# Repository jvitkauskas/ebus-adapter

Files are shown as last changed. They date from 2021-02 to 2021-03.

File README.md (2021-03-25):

# ebus-adapter

This is an open source reimplementation of adapter boards for [eBUS daemon project](https://github.com/john30/ebusd). Currently only base board v2.2 is provided.

# Base Board v2.2

! Please note this board has not been tested in real life yet !

This board was designed by [Daniel Ismail](https://github.com/daniism)

See https://ebus.github.io/adapter/base.en for more information.

EAGLE files are available in [baseboard_v2.2](baseboard_v2.2) directory.

Fabrication files (Gerber files) are available in [baseboard_v2.2/Fabrication_Files.zip](baseboard_v2.2/Fabrication_Files.zip)

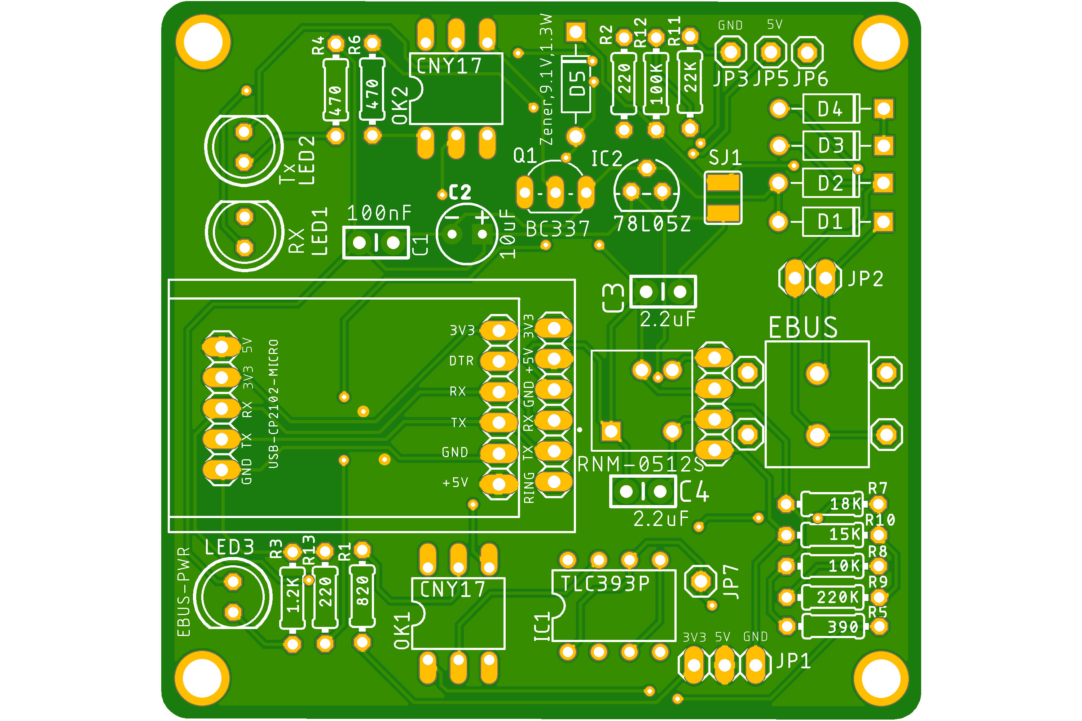
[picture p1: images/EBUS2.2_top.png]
Base Board v2.2 top image


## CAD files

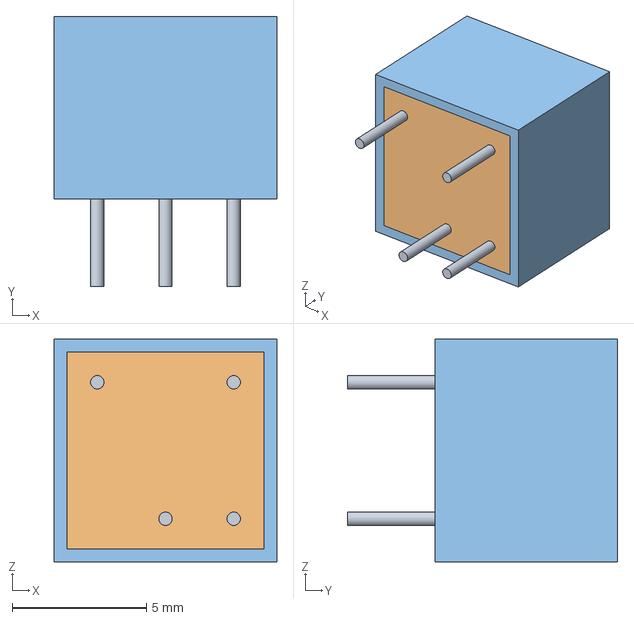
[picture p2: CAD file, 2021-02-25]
baseboard_v2.2/RNM-0512S.STEP
8.30 x 10.1 x 8.30 mm

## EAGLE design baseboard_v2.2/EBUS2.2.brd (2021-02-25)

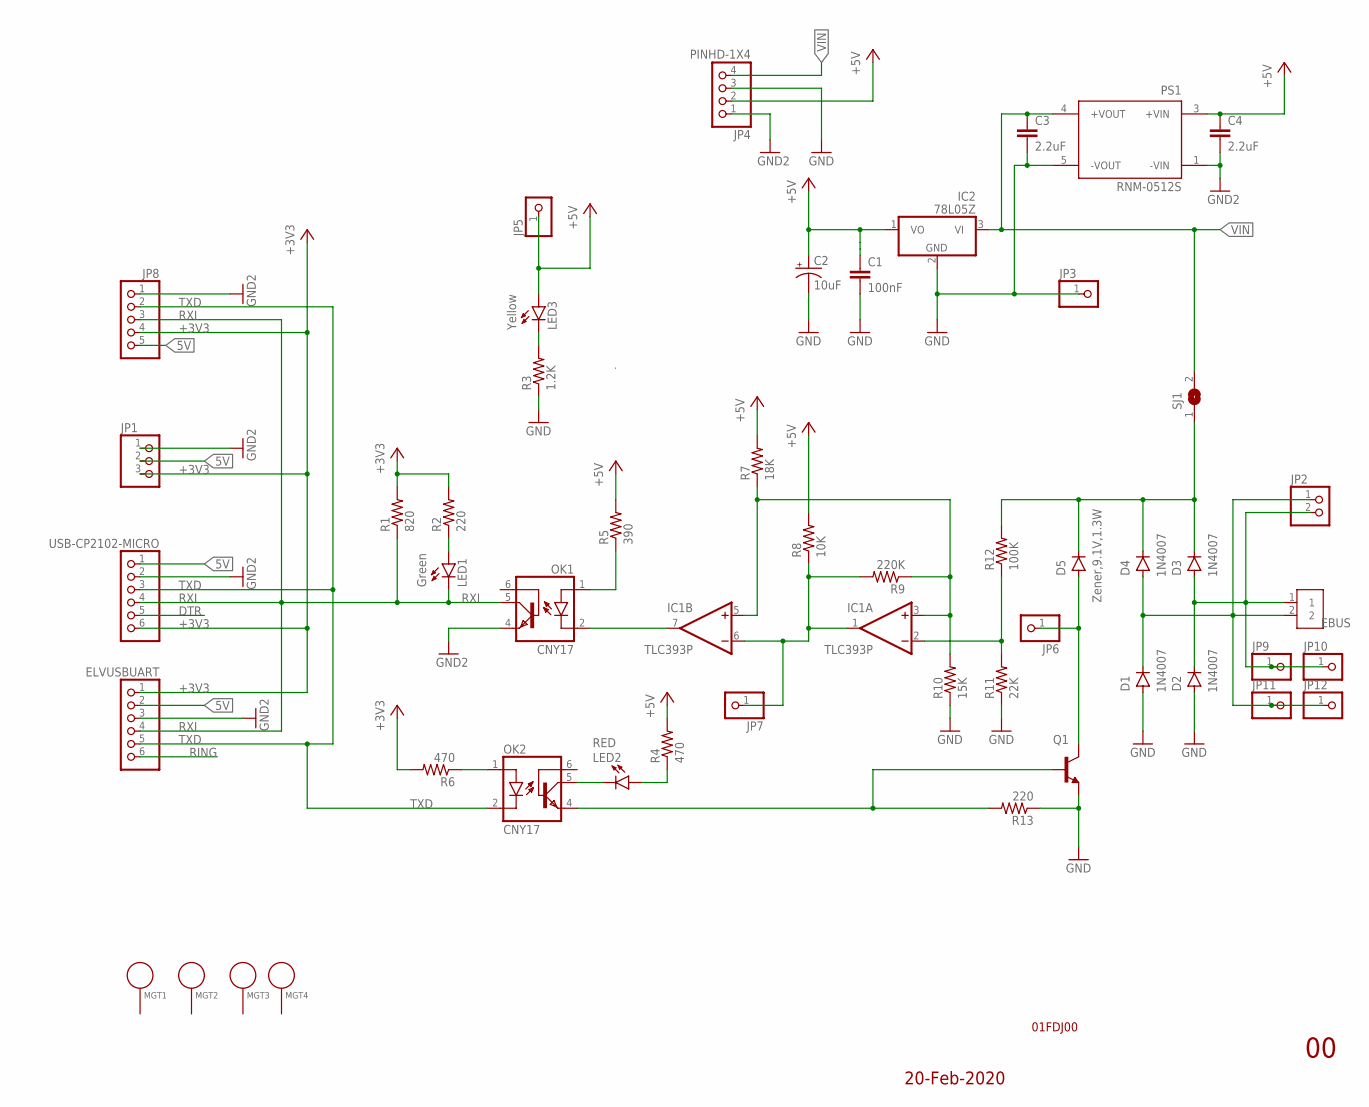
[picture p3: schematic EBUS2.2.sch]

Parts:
C1: 100nF; CAP-PTH-SMALL-KIT
C2: 10uF; CPOL-RADIAL-2.5MM-5MM-KIT
C3, C4: 2.2uF; CAP-PTH-SMALL-KIT
D1, D2, D3, D4: 1N4007; DO-41
D5: Zener,9.1V,1.3W; DO-41
EBUS: 2828XX-2282837-2; TERMBLK_508-2N
ELVUSBUART: PINHD-1X6; 1X06
IC1: TLC393P; DIL08
IC2: 78L05Z; TO92
JP1: PINHD-1X3; 1X03
JP2: PINHD-1X2; 1X02
JP3, JP5, JP6, JP7, JP9, JP10, JP11, JP12: PINHD-1X1; 1X01
JP4: PINHD-1X4; 1X04
JP8: PINHD-1X5; 1X05
LED1: Green; LED5MM
LED2: RED; LED5MM
LED3: Yellow; LED5MM
MGT1, MGT2, MGT3, MGT4: MOUNTING_HOLE; BEAGLEBONEBLACK_MOUNTING_HOLE
OK1, OK2: CNY17; DIL06
PS1: RNM-0512S; CONV_RNM-0512S
Q1: BC337-NPN-TO92-CBE; TO92-CBE
R1: 820; 0204/7
R2, R13: 220; 0204/7
R3: 1.2K; 0204/7
R4, R6: 470; 0204/7
R5: 390; 0204/7
R7: 18K; 0204/7
R8: 10K; 0204/7
R9: 220K; 0204/7
R10: 15K; 0204/7
R11: 22K; 0204/7
R12: 100K; 0204/7
SJ1: SJW
USB-CP2102-MICRO: PINHD-1X6; 1X06

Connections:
5V: ELVUSBUART.2, JP1.2, JP8.5, USB-CP2102-MICRO.1
+3V3: ELVUSBUART.1, JP1.3, JP8.4, R1.2, R2.2, R6.2, USB-CP2102-MICRO.6
+5V: C1.1, C2.1 (+), C4.1, IC2.1 (VO), JP4.2, JP5.1, LED3.A, PS1.3 (+VIN), R4.2, R5.2, R7.2, R8.2
DTR: USB-CP2102-MICRO.5
GND: C1.2, C2.2 (-), C3.2, C4.2, D1.A, D2.A, ELVUSBUART.3, IC2.2 (GND), JP1.1, JP3.1, JP4.1, JP4.3, JP8.1, OK1.4 (EMI), PS1.1 (-VIN), PS1.5 (-VOUT), Q1.E, R3.1, R10.1, R11.1, R13.1, USB-CP2102-MICRO.2
unnamed: LED3.K (C), R3.2
unnamed: LED1.A, R2.1
unnamed: LED2.A, R4.1
unnamed: IC1.7 (OUT), OK1.2 (C)
unnamed: OK1.1 (A), R5.1
unnamed: IC1.2 (-IN), R11.2, R12.1
unnamed: OK2.1 (A), R6.1
unnamed: IC1.1 (OUT), IC1.6 (-IN), JP7.1, R8.1, R9.2
unnamed: IC1.3 (+IN), IC1.5 (+IN), R7.1, R9.1, R10.2
unnamed: D3.C, D4.C, D5.C, R12.2, SJ1.1
unnamed: LED2.K (C), OK2.5 (COL)
unnamed: D5.A, JP6.1, Q1.C
unnamed: D2.C, D3.A, EBUS.1, JP2.2, JP9.1, JP10.1
unnamed: D1.C, D4.A, EBUS.2, JP2.1, JP11.1, JP12.1
unnamed: OK2.4 (EMI), Q1.B, R13.2
RING: ELVUSBUART.6
RXI: ELVUSBUART.4, JP8.3, LED1.K (C), OK1.5 (COL), R1.1, USB-CP2102-MICRO.4
TXD: ELVUSBUART.5, JP8.2, OK2.2 (C), USB-CP2102-MICRO.3
V+: IC1.8 (V+)
V-: IC1.4 (V-)
VIN: C3.1, IC2.3 (VI), JP4.4, PS1.4 (+VOUT), SJ1.2

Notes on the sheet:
20-Feb-2020
01FDJ00

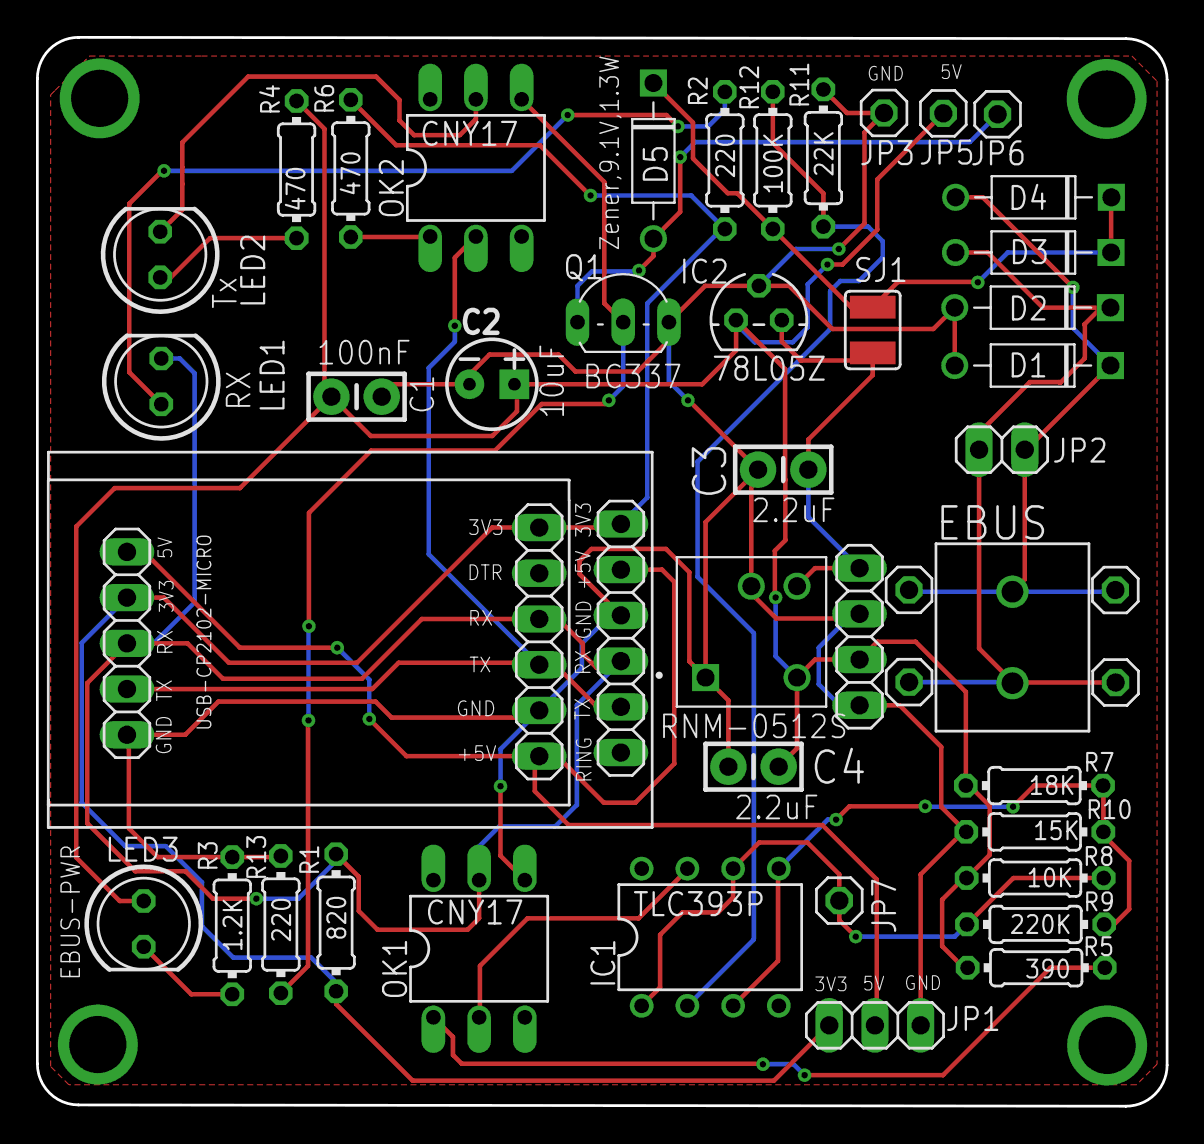
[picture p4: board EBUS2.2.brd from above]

Board: 2 copper layers, 62.8 x 59.4 mm, 51 parts (0 on the bottom side), 22 nets.

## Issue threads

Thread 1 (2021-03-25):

Testers needed

jvitkauskas, 2021-03-25:
Baseboard v2.2 has not been tested in real life yet. In case somebody has tested it and it works, I would be interested to know if it works.

ashumkin, 2021-05-13:
I've also found the error with the "external power" option )) It has the common ground with the ebus-line but the description says "galvanically isolated"
So, I've fixed the error by cutting two routes and making two additional "jumpers" )
So, the board works with my fixes ))

ashumkin, 2021-05-13:
Also, I'd propose to change a form-factor of a board to be able to insert it into a DIN-rail box, for example

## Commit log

2021-02-25 Add base board v2.2
    [EBUS2.2.brd, EBUS2.2.sch, RNM-0512S.STEP]
2021-02-26 Add Base Board v2.2 top image

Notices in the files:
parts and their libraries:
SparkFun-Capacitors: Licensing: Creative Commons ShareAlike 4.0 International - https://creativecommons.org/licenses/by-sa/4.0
